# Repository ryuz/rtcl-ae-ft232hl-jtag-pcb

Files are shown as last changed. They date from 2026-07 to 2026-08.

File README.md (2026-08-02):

# FT232HLを JTAG 用に変換する基板

[English](README_en.md)

秋月電子さんの[FT232HL ハイスピードUSBシリアル変換モジュール](https://akizukidenshi.com/catalog/g/g106503/) を、JTAG 用に変換する基板を作りました。

主に拙作の [Tang Primer25K用USB3.0基板](https://github.com/ryuz/rtcl-tp25k-usb3-pcb) で利用することを想定しています。

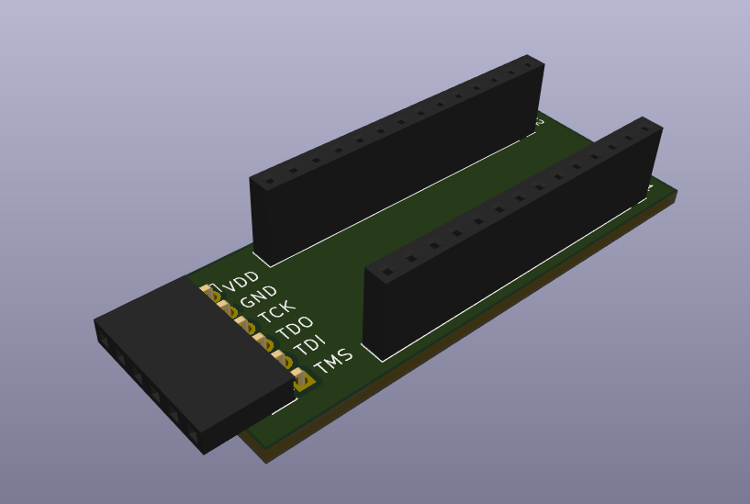
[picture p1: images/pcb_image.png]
PCBイメージ


一本づつ繋がなくて良くなるので、抜き差しがとても楽になります。

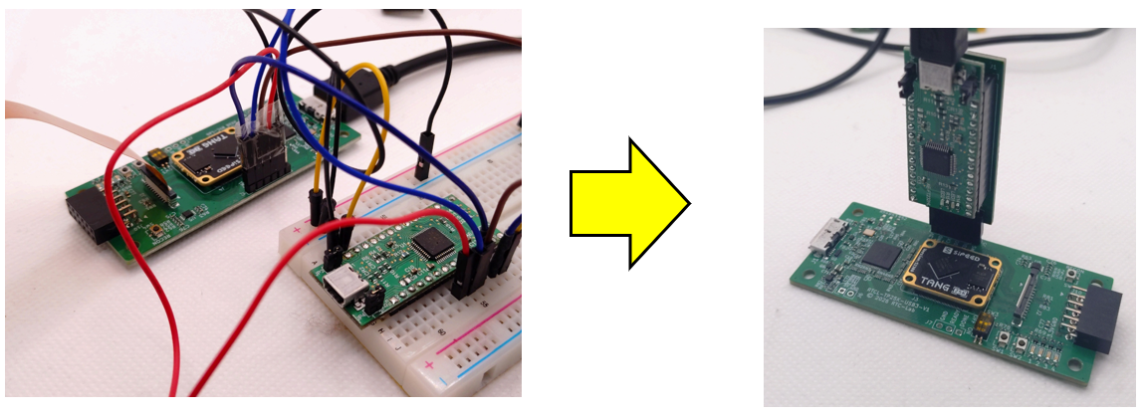
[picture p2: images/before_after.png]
before_after


## 使い方

使用時の利便性を加味して、半田面にもシルク印刷していますので、コネクタを半田付けするときは表裏を間違えないように注意してください。

J1/J2/J3 などのリファレンスが印字されている側が部品面です。

FT232HL ハイスピードUSBシリアル変換モジュールは側は JP3 のみショートさせ、 **JP4は必ずオープンにしてください**。

JP4は I/O 電圧を供給するものですが、今回は接続先のボードから電圧を取るように設計しており、もし JP4 を繋ぐと FT232HL 側からも 3.3V電圧が供給されてしまい電源電圧の衝突で **ボードが壊れる可能性** があります。

## 免責事項

本設計データは、研究開発用の試作実験に用するものであり、利用に際して発生した如何なる損害も作者は補償いたしませんので予めご了承ください。

## ライセンス(License)

本設計データは、[クリエイティブ・コモンズ 表示-非営利 4.0 国際 ライセンス](https://creativecommons.org/licenses/by-nc/4.0/deed.ja)の下で提供されています。

製造した本基板の無断での販売や配布を行わない限りは、趣味や研究開発用途でご自由にお使いいただく事が出来ます。

また、商用に製造販売を希望される場合は、別途ライセンス契約を作者までご相談ください。[お問い合わせフォーム](https://rtc-lab.com/contact/)などからお問い合わせ頂けます。

## 作者情報

渕上 竜司(Ryuji Fuchikami)
[リアルタイムコンピューティング研究所](https://rtc-lab.com/)

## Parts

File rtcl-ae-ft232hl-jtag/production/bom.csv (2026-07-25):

Designator | Footprint | Quantity | Value | LCSC Part #
J1, J2 | PinSocket_1x14_P2.54mm_Vertical | 2 | Conn_01x14
J3 | PinSocket_1x06_P2.54mm_Horizontal | 1 | Conn_01x06

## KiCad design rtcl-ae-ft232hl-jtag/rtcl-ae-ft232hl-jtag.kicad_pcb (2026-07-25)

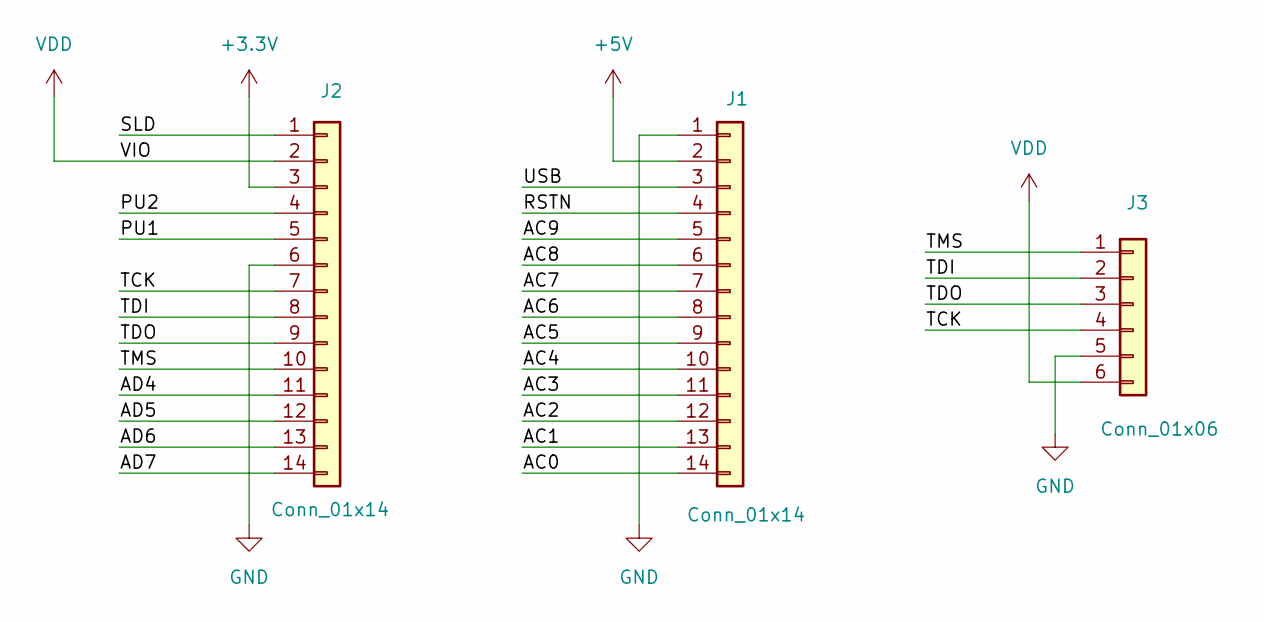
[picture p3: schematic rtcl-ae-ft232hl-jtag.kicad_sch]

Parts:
J1, J2: Conn_01x14; PinSocket_1x14_P2.54mm_Vertical
J3: Conn_01x06; PinSocket_1x06_P2.54mm_Horizontal

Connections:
+3.3V: J2.3
+5V: J1.2
/AC0: J1.14
/AC1: J1.13
/AC2: J1.12
/AC3: J1.11
/AC4: J1.10
/AC5: J1.9
/AC6: J1.8
/AC7: J1.7
/AC8: J1.6
/AC9: J1.5
/AD4: J2.11
/AD5: J2.12
/AD6: J2.13
/AD7: J2.14
/PU1: J2.5
/PU2: J2.4
/RSTN: J1.4
/SLD: J2.1
/TCK: J2.7, J3.4
/TDI: J2.8, J3.2
/TDO: J2.9, J3.3
/TMS: J2.10, J3.1
/USB: J1.3
GND: J1.1, J2.6, J3.5
VDD: J2.2, J3.6

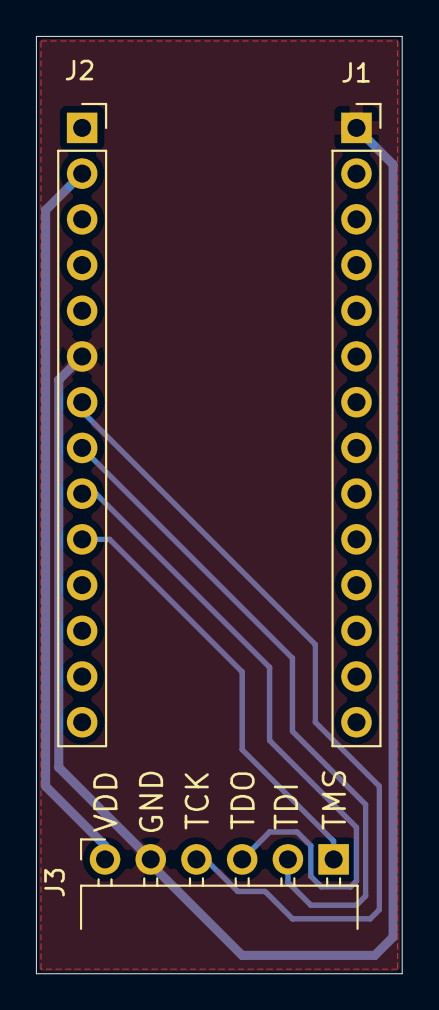
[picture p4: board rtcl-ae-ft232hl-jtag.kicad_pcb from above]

Board: 2 copper layers, 20.3 x 52.1 mm, 3 parts (0 on the bottom side), 6 nets.

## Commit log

2026-07-25 1st commit
    [rtcl-ae-ft232hl-jtag.kicad_pcb, rtcl-ae-ft232hl-jtag.kicad_sch]
2026-07-25 Enable island removal in PCB design settings
    [rtcl-ae-ft232hl-jtag.kicad_pcb]
2026-07-25 Update KiCad project settings for improved layer visibility and clearance
    - Changed active layer from 2 to 7 in the .kicad_prl file to enhance design focus.
    - Updated layer visibility settings: enabled text display and disabled track display.
    - Adjusted zone display mode from 0 to 1 for better zone management.
    - Modified solder mask to copper clearance from 0.0 to 0.005 in the .kicad_pro file for improved manufacturing tolerances.
    [bom.csv, designators.csv, positions.csv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]
2026-07-25 Add PCB image and update README with disclaimer, license, and author information
2026-07-31 Add English README for FT232HL to JTAG conversion board
2026-08-02 Add usage instructions and warnings to README for FT232HL JTAG conversion board
2026-08-02 Update README with detailed usage instructions for FT232HL JTAG conversion board

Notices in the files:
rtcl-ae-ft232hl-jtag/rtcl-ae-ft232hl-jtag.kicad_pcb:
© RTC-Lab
